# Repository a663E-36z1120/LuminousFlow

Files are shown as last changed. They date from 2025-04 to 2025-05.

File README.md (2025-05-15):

# 🌊 **Project Luminous Flow**
***Real-time fluid simulation on an LED matrix display*** responding to ***live accelerometer data***, rendered at 60+ FPS by a ***simple GPU built from scratch*** with Arduino and logic IC chips — continuum mechanics in a purely digital circuit!

<p float="left">
  
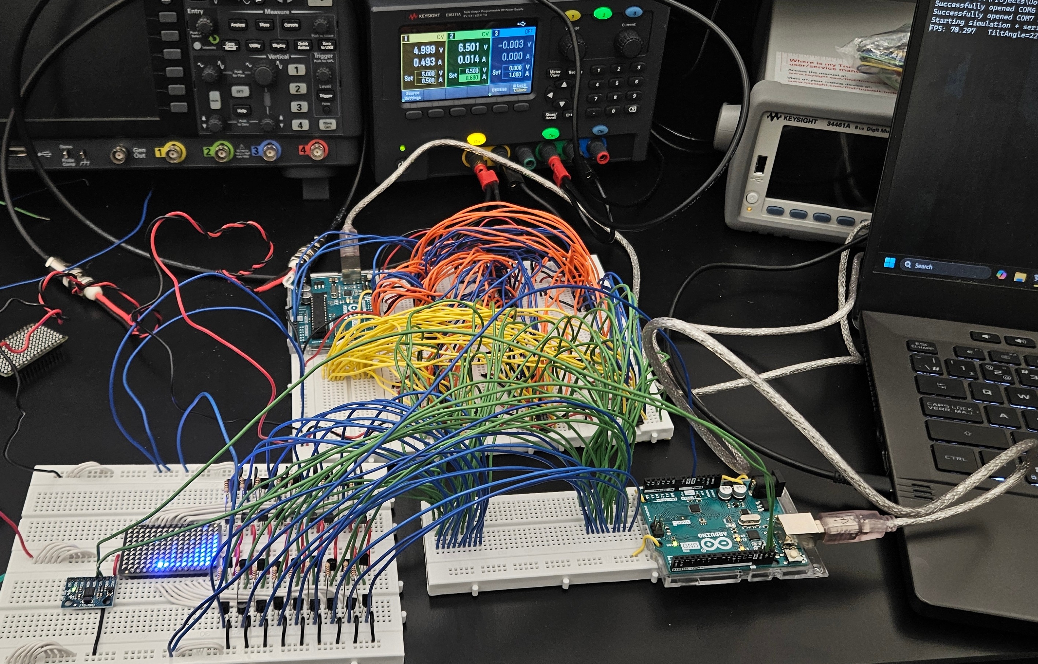
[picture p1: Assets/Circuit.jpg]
  
</p>

## Physics Engine
The physics engine of our fluid simulation implements [Smoothed-particle hydrodynamics (SPH)](https://en.wikipedia.org/wiki/Smoothed-particle_hydrodynamics) proposed by Gingold and Monaghan in 1977 [[1]](#1). This can be found in [SPHEngine.cpp](SPHEngine.cpp), which in every cycle takes as input a 2D instantaneous global acceleration in polar coordinates to update the positions of particles in the simulation.

💡 If you want to use our physics engine for your own project, we've included an isolated version of it in [Prototyping/SPHEnginePybind.cpp](Prototyping/SPHEnginePybind.cpp) that you can interact with through a Jupyter notebook such as [Prototyping/physics_testbench.ipynb](Prototyping/physics_testbench.ipynb), thanks to the [pybind11](https://github.com/pybind/pybind11) project. A Python implementation that we used in the early stages of this project is also available in [Prototyping/physics_testbench_py.ipynb](Prototyping/physics_testbench_py.ipynb).

⚠️ Please note that this physics engine is designed to be compiled and ran on a PC instead of a microcontroller.

<p float="left">
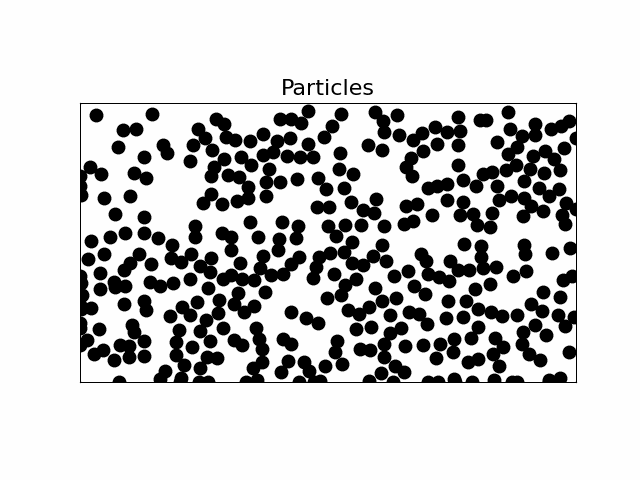
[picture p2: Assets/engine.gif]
  
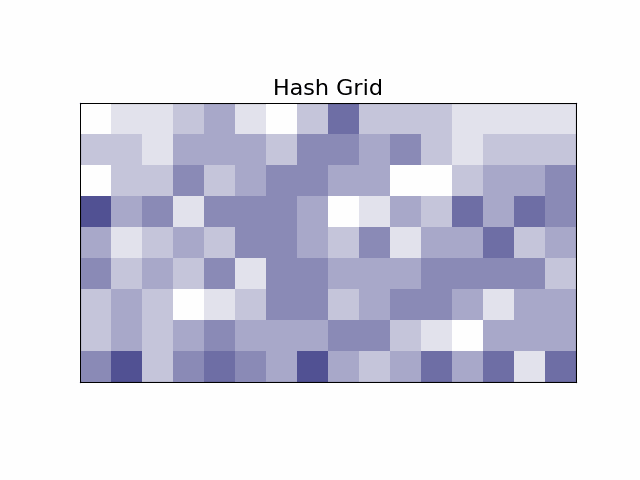
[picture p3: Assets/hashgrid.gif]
  
</p>

___

<a id="1">[[1]](https://academic.oup.com/mnras/article/181/3/375/988212)</a> 
Gingold, R. A., & Monaghan, J. J. (1977). *Smoothed particle hydrodynamics: theory and application to non-spherical stars.* Monthly notices of the royal astronomical society, 181(3), 375-389.

Created by 
[@a663E-36z1120](https://www.github.com/a663E-36z1120)
&
[@AlexZengXi](https://www.github.com/AlexZengXi); shoutout to [Prof. Ziqing Hong](https://zqhong.physics.utoronto.ca/) from the Department of Physics at University of Toronto for teaching the amazing [PHY405H1: Electronics Lab](https://artsci.calendar.utoronto.ca/course/phy405h1) course and supporting this project!

___

# **Detailed Technical Documentations for the Nerds**

*Figure 1: Project Luminous Flow in Its Entirety *

## System Architecture
We are designing an interactive LED matrix that simulates fluid motion in response to the system's tilt. Figure 2 shows the functional block diagram of the system. 

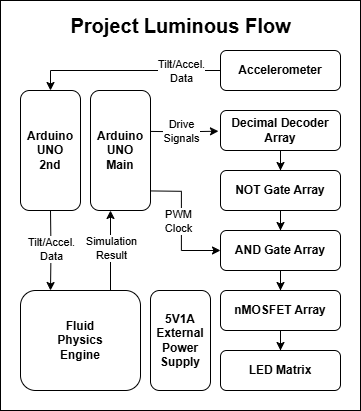
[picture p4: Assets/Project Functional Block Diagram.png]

*Figure 2: Functional Block Diagram*

As illustrated in Figure 1, the system architecture is divided into three primary sections. The far-right segment comprises four full-sized breadboards, collectively housing our custom-designed GPU. This region includes the main Arduino UNO, responsible for generating all driving signals, and the array of logic IC chips that help distribute the signals.

To the left, a pair of breadboards make up the LED display section. This section houses the 16×9 LED matrix, the accelerometer, all the nMOSFETs, and the current-limiting resistors.

Finally, the single breadboard in between acts as an interface board. It organizes the signal connections from the logic gate array to the LED display, simplifying testing and debugging. This board also holds the secondary Arduino, which relays accelerometer data to the physics engine for real-time simulation. 

The Build of Materials can be found below in Table 1.

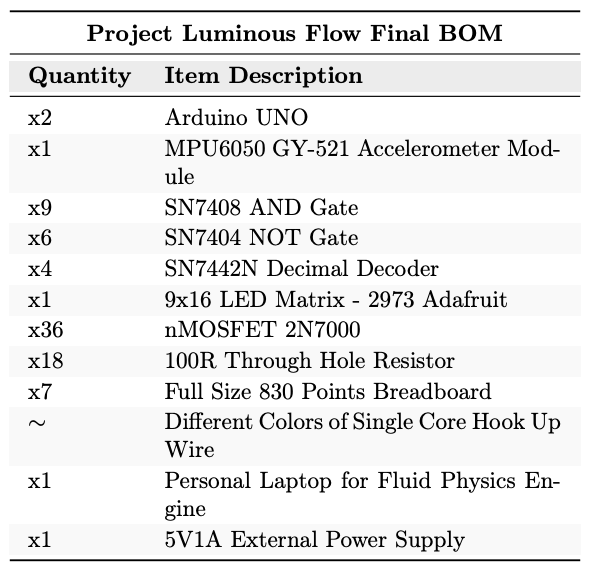
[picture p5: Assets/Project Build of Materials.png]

*Table 1: Build of Materials*

## Fluid Physics Engine
The physics engine of our fluid simulation implements Smoothed-particle hydrodynamics (SPH) as proposed by Gingold and Monaghan in 1977. Pseudo-code outlined by the Algorithm describes how our implementation of the SPH physics engine operates.

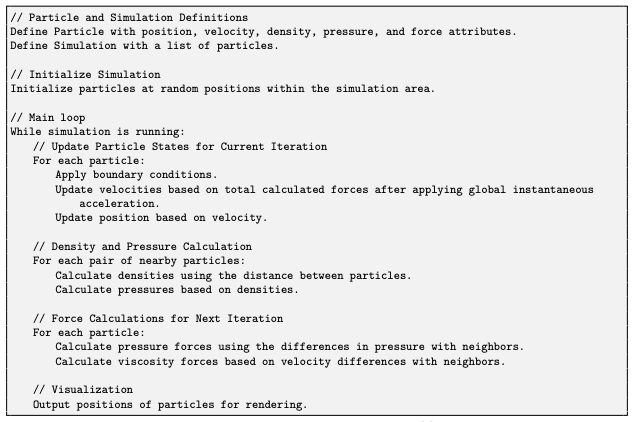
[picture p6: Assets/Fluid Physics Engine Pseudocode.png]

*Algorithm 1: Core Abstract Operations of the SPH Physics Engine*

Every cycle of our physics engine takes as input a 2D instantaneous global acceleration in polar coordinates and outputs to update the positions of particles in the simulation.

## Accelerometer
We are using an MPU6050 GY-521 Accelerometer Module. It communicates to our secondary Arduino UNO through I2C and then feeds serial data to the physics engine. Given that our simulation is 2D while our accelerometer supplies acceleration vectors in 3D, we project $\vec{a} = (x, y, z)$ onto the $xy$-plane and compute:

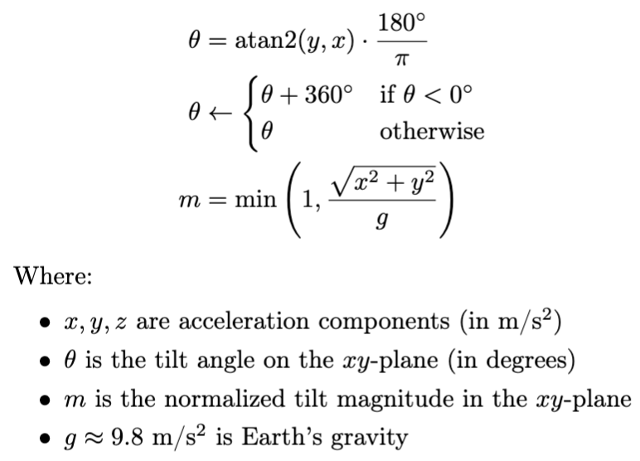
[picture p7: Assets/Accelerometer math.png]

*Algorithm 2: Core Abstract Operations of the SPH Physics Engine*

This projected and normalized polar form accelerometer data $(\theta, m)$ is what we input into our physics engine.

## Communication Protocol 
The system establishes two serial communication channels between the PC that runs the SPH physics simulation and two Arduinos. The first Arduino is connected to an MPU6050 accelerometer via I²C and continuously transmits orientation data to the PC over USB serial at 115200 baud. Each packet is 9 bytes long, consisting of a 1-byte header (0xFE), followed by two 4-byte `float` values: the tilt angle and normalized magnitude. These values are packed in little-endian order and sent as raw binary data.

On the PC side, this data is received asynchronously and used to update a real-time 2D smoothed particle hydrodynamics (SPH) simulation. The new gravity direction is derived from the received tilt values and applied to the particle system. The resulting particle positions are mapped to a $9 \times 16$ LED grid using a uniform hash grid, where local particle density is converted into brightness values in the range $[0, 255]$.

A second serial connection is established between the PC and a second Arduino responsible for controlling the LED matrix (the "GPU Arduino") also at 115200 baud. A hash grid maps continuous particle positions from the physics simulation into discrete LED grid cells by counting particle density per cell, which is then linearly scaled to individual pixel brightness in a frame. The PC sends full display frames as 145-byte binary packets, consisting of a 1-byte header (0xFF), followed by 144 brightness bytes (row-major order). These values are packed in little-endian order and sent as raw binary data. The GPU Arduino receives these frames and renders them to the physical display using a Charlieplexing scheme with bit-banged 4-bit output codes. Brightness is modulated using PWM control, allowing smooth intensity transitions.

## Graphics Processing Unit
We constructed a simple GPU from an Arduino Uno and logic IC chips listed on Table 1 to be able to render our physics engine at a frame rate that seems realistic to the naked eye on our LED matrix display. As shown on Table 3, the LED matrix display requires 36 unique digital pins to address all pixels on our display while our physics simulation will appear more compelling if we are able to control the brightness of every pixel independently. However, the Arduino Uno only has 20 GPIO pins, out of which only 6 can support PWM. Our GPU firmware overcomes this limitation by employing a bit-banging technique that encodes the signal for each half of the LED display into 4-bit binary values. Specifically, the left and right halves of the display are each driven by two sets of 4 GPIO pins—one set for the positive rail and one for the negative rail—totaling 16 GPIO pins, as shown on Table 2. For every pixel, the firmware determines a pair of 4-bit little-endian codes that specify the required output on the positive and negative rails, respectively, according to a pre-defined Charlieplexing lookup table. PWM signal to control the brightness of every pixel originates from a single pin (Pin 11).


*Table 2: Arduino Bit-Bang Pin Mapping for Addressing the Multiplexed LED Matrix. (See Table 3: Pixel Addressing) Pin 11 is used for the PWM Signal Broadcast. *

At the hardware level, each of our 4-bit encoded binary control signals from the Arduino Uno is first decoded with SN7442N decimal decoders. The SN7442N decodes our 4-bit binary control signal to one of its 10 output pins outputting low voltage while all other 9 output pins output high voltage. We want the opposite—where only 1 pin outputs high while the rest output low—so we pass the decoded signal through SN7404 hex inverters, which are effectively an array of NOT gates that invert the decoded signals to what we want. Finally, we pass this inverted signal and a broadcasted PWM signal from Pin 11 through SN7408 binary AND gates to give our control signal the desired duty cycle to control the brightness of the pixel it drives. The output from the AND gate arrays are the final digital output signals to the LED matrix display. The constructed circuit of our GPU can be seen in Figure 3.

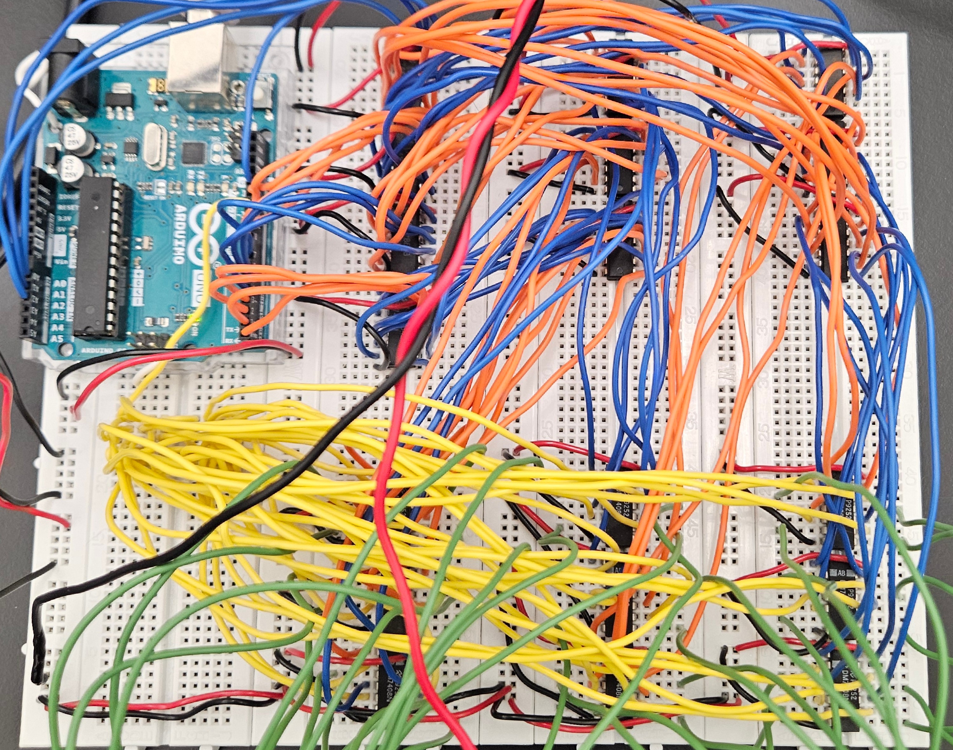
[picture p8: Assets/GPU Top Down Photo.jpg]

*Figure 3: Photo of the GPU we constructed. On the rightmost 3 breadboard columns: **top left:** 4x SN7442N decimal decoder array. **top center & top right:** 6x SN7404 hex inverter (NOT gate) array. **bottom left, center, & right:** 9x SN7408 AND gate array. Wire colors: **Orange & Blue:** internal digital signal wires, alternates every 4 bit and after passing through NOT gates. **Yellow:** PWM signal broadcast wires. **Green:** Output signal wires. **Red:** 5V Vcc. **Black:** Ground.*

## LED Matrix and nMOSFET Array
We are using the Adafruit 2973 16x9 blue LED matrix to display the behavior of water under varying tilt angles. This matrix comprises 144 individual LEDs, and driving each LED with a separate GPIO pin would be impractical. Instead, we employ a common technique called multiplexing. Specifically, this board utilizes a row-column multiplexing method. 

The 16x9 LED matrix is internally structured as two independent 8x9 LED matrices, Matrix A and Matrix B. Each of these 8x9 matrices is controlled by nine dedicated pins, as illustrated in the schematic (Figure 4 or the project's GitHub page for a higher-resolution image). Each of these nine pins is connected to a pair of 2N70000 nMOSFETs. One MOSFET, when the gate receives an activation signal, connects the pin to ground. The other MOSFET, when activated, connects the pin through a 100R current-limiting resistor to the 5V power supply. It is also worth noting that the connections for each row and column are unique and should be carefully examined. 

LEDs are unidirectional devices, meaning they only emit light when current flows through them in the forward direction. Additionally, in a multiplexed matrix, even if an LED has the correct forward voltage across it, if a lower-resistance path from another LED exists for the current, the current won't go through other LEDs. This current flow characteristic dictates how we can selectively activate individual LEDs within the matrix. 

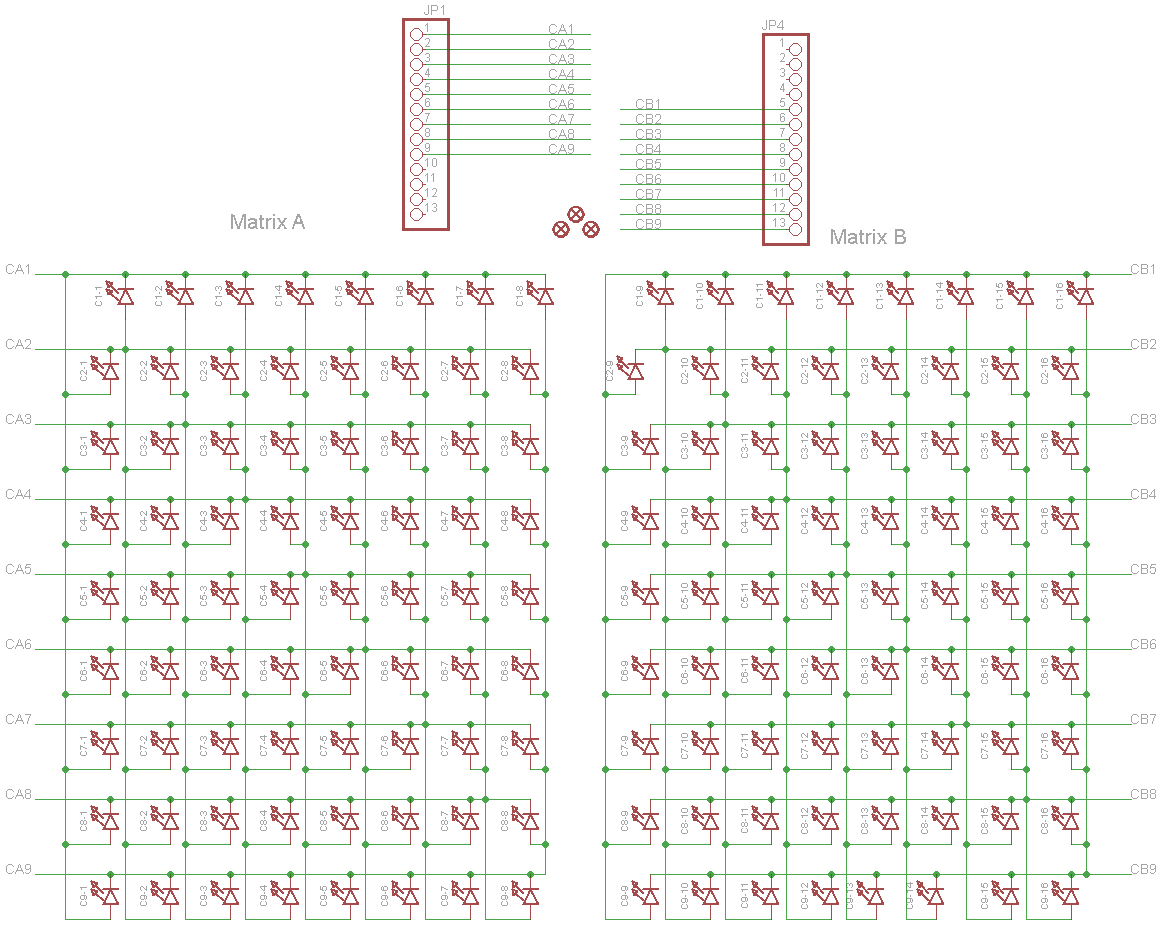
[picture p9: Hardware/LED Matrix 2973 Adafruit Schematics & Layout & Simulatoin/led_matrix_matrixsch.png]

*Figure 4: 2973 Adafruit 16x9 Blue LED Matrix Schematic*

By precisely controlling which of the nine control lines are driven high (connected to approximately 5V through a current-limiting resistor) and which are driven low (connected to ground) at any given moment, we can create a specific voltage potential across only the desired LED, ensuring current flows through it and no other unintended paths are completed. Rapidly switching these control line states allows us to create the illusion of a stable display with individual pixel control using fewer pins than the total number of LEDs. 

Each submatrix of the 16×8 LED display requires nine control pins, resulting in a total of eighteen control pins for the full board. Since each control pin is connected to two nMOSFETs, the system needs to control 36 nMOSFETs to operate the entire display. While this is still far fewer than the 128 GPIO pins that would be needed to control each LED individually, 36 GPIO pins is still beyond what an Arduino UNO can provide. Additionally, to create a more lifelike fluid simulation, we aim to vary the brightness of the LEDs—requiring 36 PWM-capable outputs, which is impractical without designing a custom shield board from scratch. 

After extensive brainstorming, we developed a simple yet effective solution using only the logic gate components available in our physics lab. More information on this is explained in the earlier GPU section. 

We use 2N7000 through-hole nMOSFETs to pull the LED display control pins high or low. The schematic for a typical control pin setup is shown in Figure \ref{p4}. All MOSFETs are controlled by the logic gate array and the Arduino, based on output from the fluid physics engine. Although the Arduino’s GPIO pins output around 5V, after passing through logic gates, various wire lengths, and the breadboard, the voltage reaching the nMOSFET gates remains above 4V, still well above the gate threshold voltage and safely below the maximum voltage rating. 

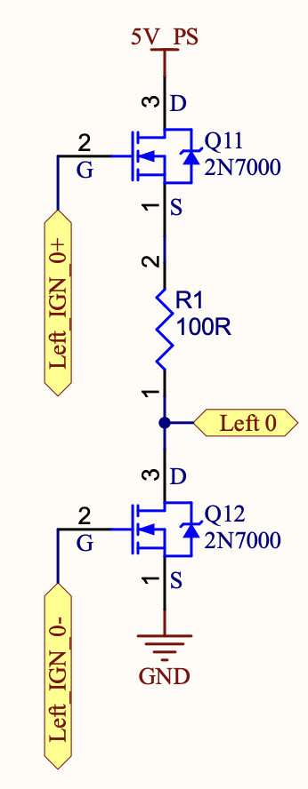
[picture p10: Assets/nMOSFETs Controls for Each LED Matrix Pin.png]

*Figure 5: Schematics of the Pull-Up and Pull-Down Setup for Control Pin 0 from the LED Matrix as Example*

When an nMOSFET receives a turn-on signal, it allows current to flow from drain to source. For the pull-up configuration, the drain is connected to the 5V rail, and the source is connected to a 100R current-limiting resistor, which then connects to the LED control pin. In the pull-down configuration, the source is connected to ground, and the drain is connected to the LED control pin. We intentionally swap the drain and source for the pull-down setup because during testing, we found that not doing so created unwanted current paths to ground, unintentionally activating multiple LEDs at once. 

In our row-column multiplexing method, to keep the firmware simple, we only turn on one LED per submatrix at a time. To create the illusion of a smooth and continuous pattern across the entire display, the system must run at a very high refresh rate. As a final precaution, we verified the switching speed of the 2N7000 MOSFETs. Both the turn-on and turn-off times are approximately 10ns \cite{2n7000}, corresponding to a theoretical switching frequency of up to 50MHz. However, accounting for real-world delays such as gate charging and discharging, we introduced a slight delay between operations. 

Since only one LED is active at any given moment, the 100R current-limiting resistor is selected based on the current requirements of a single blue LED operating at 5V. 

To simplify debugging and quickly determine which pins need to be pulled high or low, we created a lookup table, as shown in Table 3. This table is then used in the firmware to control the corresponding MOSFETs for each LED.

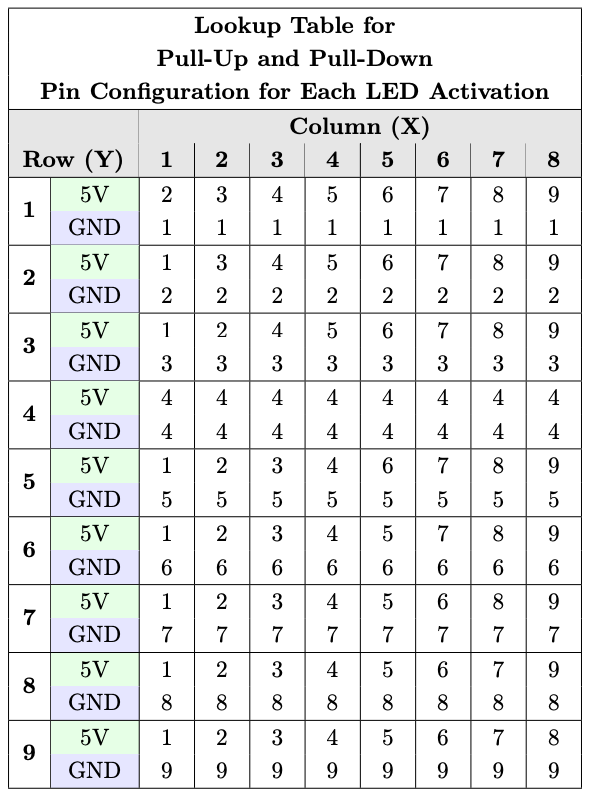
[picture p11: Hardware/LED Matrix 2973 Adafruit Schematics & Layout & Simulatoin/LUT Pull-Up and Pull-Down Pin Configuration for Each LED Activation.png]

*Table 3: Configuration values for LED matrix control. For each LED position, the table shows which pins should be set to 5V and which to GND*

## Power Supply
For this project, we used a Keysight E36311A as an external power supply. As a safety precaution, we powered the LED display and the accelerometer using one 5V channel, while a second 5V channel supplied power to the rest of the system. Using two separate channels allowed us to monitor the current draw of each section independently, which proved helpful during debugging. 

Since only one LED is active at a time, the power consumption of the first 5V channel remained very low, drawing less than 10mA in total. However, the logic gate array drew approximately 0.5A, far exceeding what the Arduino UNOs can provide. This made an external power supply essential for everything to work. 

Although the power supply may not deliver exactly 5V, small ripples and voltage offsets are still within the acceptable range to reliably power our entire system. Similarly, while the current readings may not be perfectly accurate, they are sufficient for identifying anomalies. In practice, if something is wired incorrectly, the current draw typically spikes and quickly hits the 0.6A current limit, providing a clear indication that something is wrong. 

Both 5V channels from the external power supply and the two Arduino UNOs share a common ground to ensure proper signal referencing and avoid potential floating ground issues.

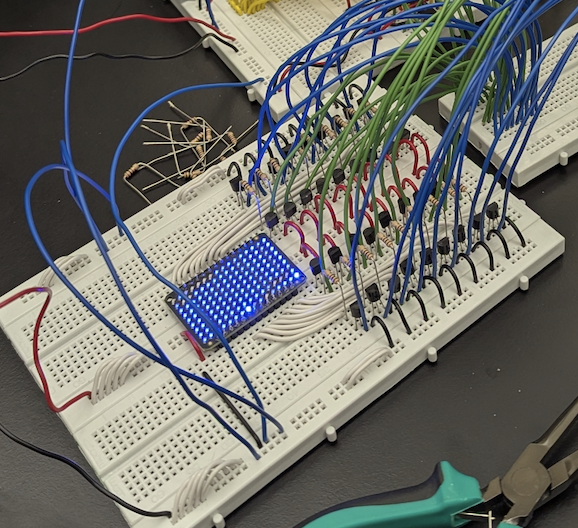
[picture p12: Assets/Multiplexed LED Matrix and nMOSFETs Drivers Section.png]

*Figure 6: Photo of the LED Display and Driver Section, consists of 36x 2N7000 nMOSFETs, 16x 100R Resistors and the LED display. (the accelerometer is missing in this photo). Wire colors: **Green & Blue on the right:** nMOSFETs' gate signal wires connecting to the interface board. **White:** Wires Connecting to the LED display. **Red:** 5V Power Supply. **Black:** Ground.**

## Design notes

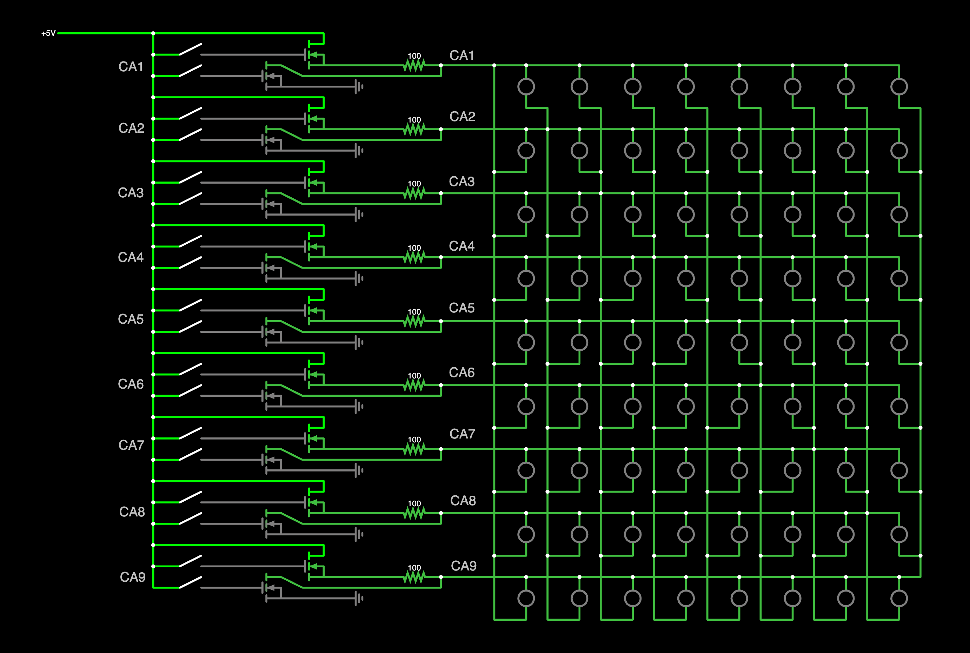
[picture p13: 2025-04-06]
Hardware/LED Matrix 2973 Adafruit Schematics & Layout & Simulatoin/LED Matrix and Drivers Falstad Simulation Screenshot.png

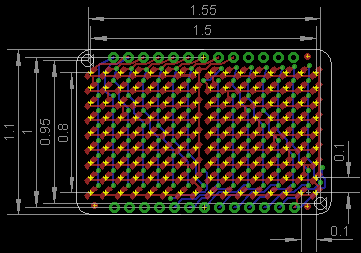
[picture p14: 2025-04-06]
Hardware/LED Matrix 2973 Adafruit Schematics & Layout & Simulatoin/led_matrix_schemgrid.png

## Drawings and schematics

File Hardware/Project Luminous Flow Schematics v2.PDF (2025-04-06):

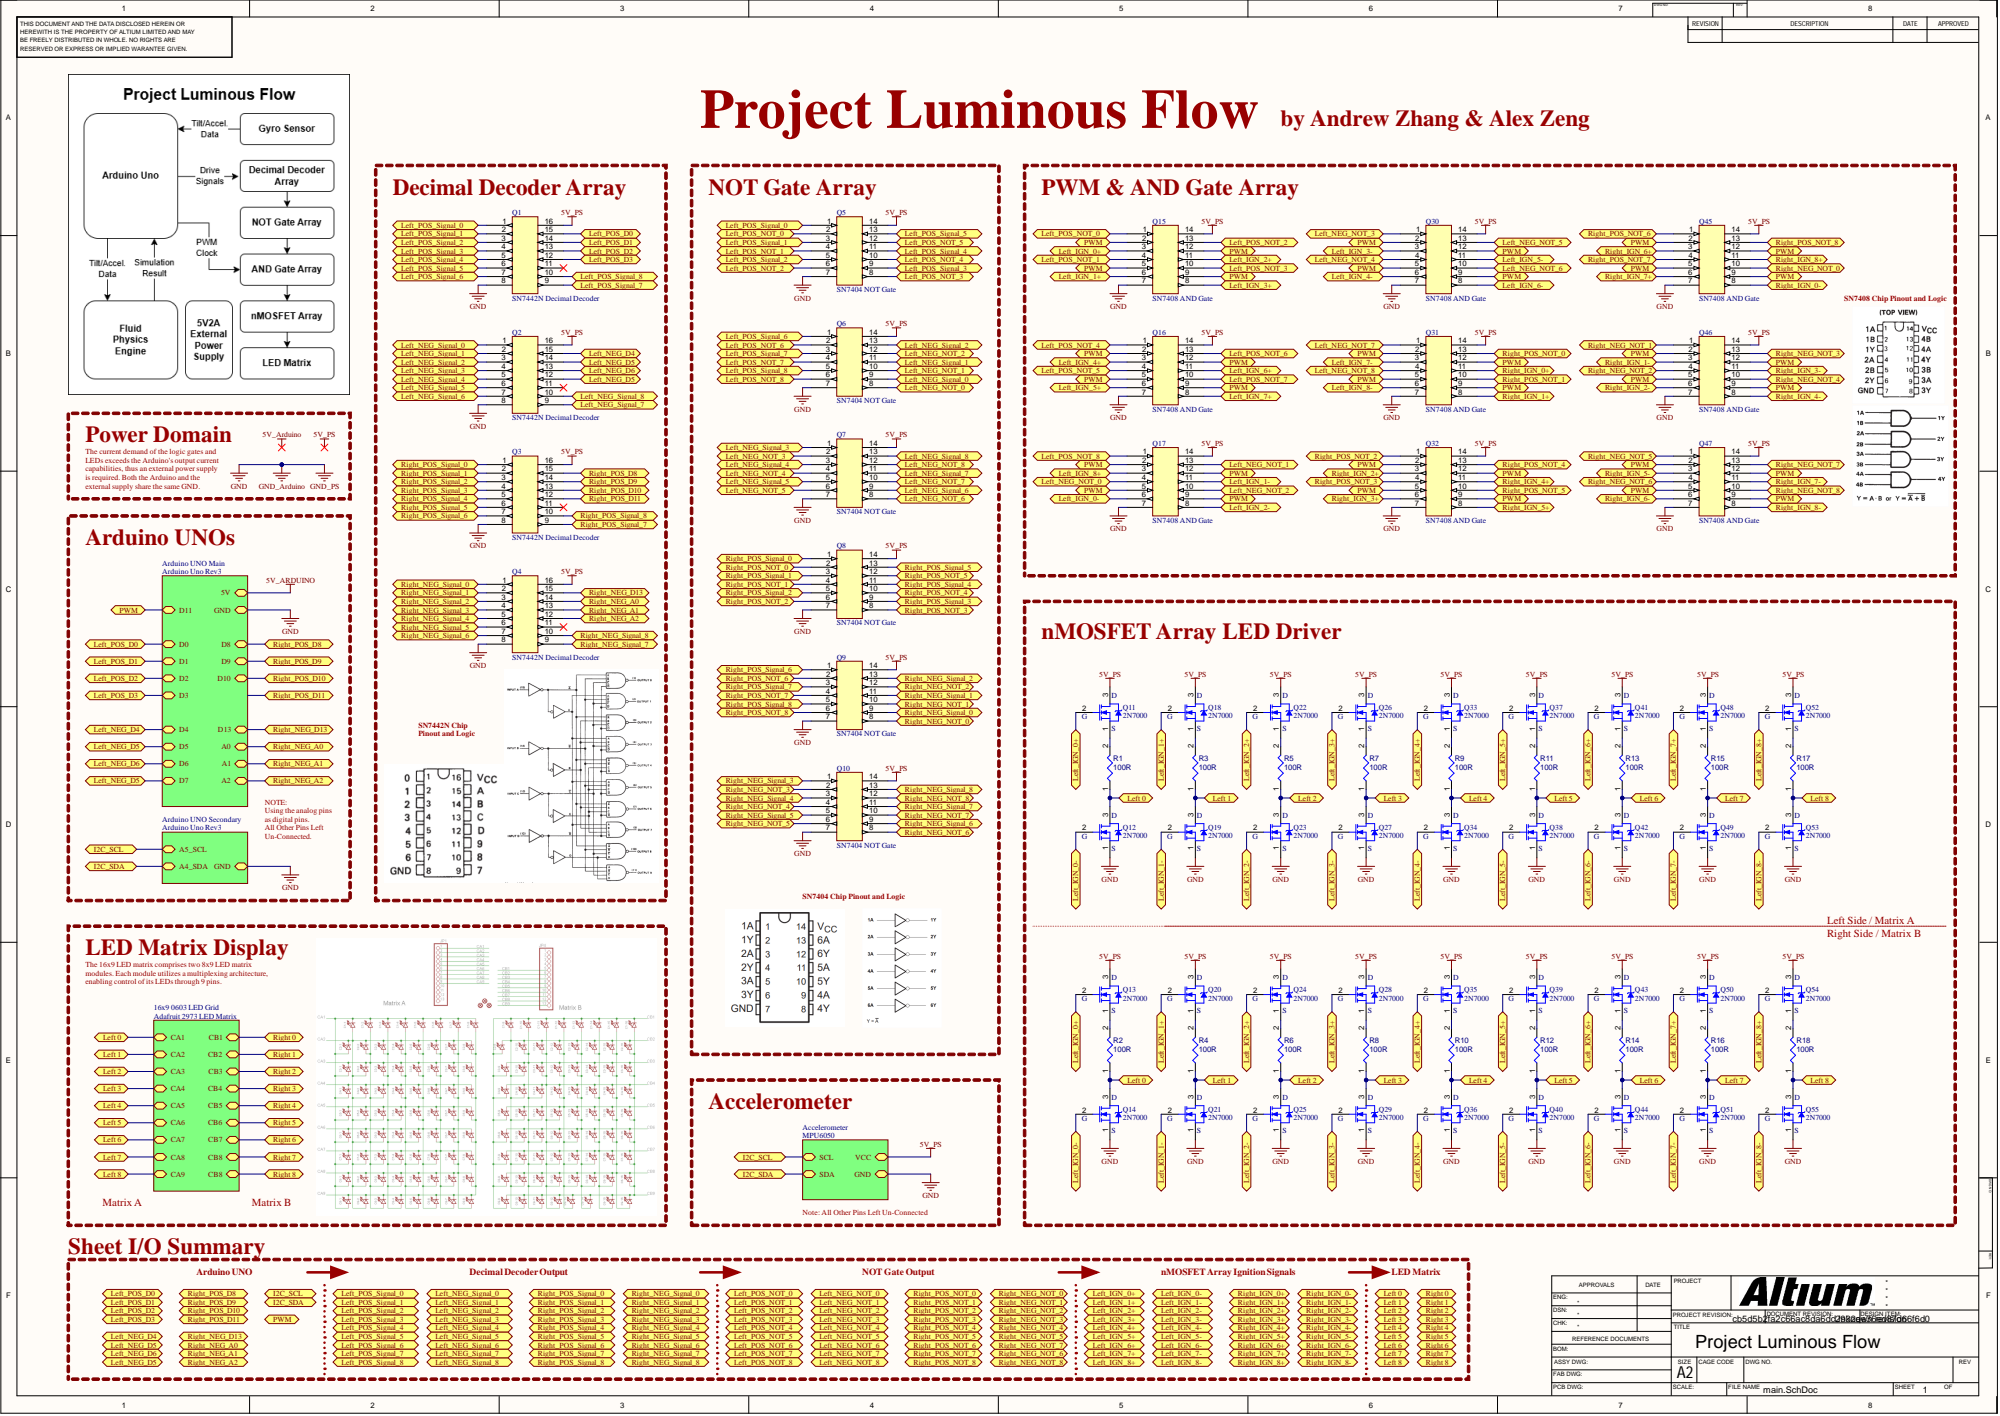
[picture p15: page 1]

DWG NO: | REV:

THIS DOCUMENT AND THE DATA DISCLOSED HEREIN OR HEREWITH IS THE PROPERTY OF ALTIUM LIMITED AND MAY BE FREELY DISTRIBUTED IN WHOLE. NO RIGHTS ARE RESERVED OR EXPRESS OR IMPLIED WARANTEE GIVEN. | Project Luminous Flow by Andrew Zhang & Alex Zeng PWM & AND Gate Array Q5 5V_PS | REVISION | DESCRIPTION | DATE | APPROVED

SN7408 Chip Pinout and Logic

The current demand of the logic gates and
LEDs exceeds the Arduino's output current
capabilities, thus an external power supply
is required. Both the Arduino and the
external supply share the same GND.

nMOSFET Array LED Driver

NOTE:
Using the analog pins
as digital pins.
All Other Pins Left
Un-Connected.

SN7404 Chip Pinout and Logic

The 16x9 LED matrix comprises two 8x9 LED matrix
modules. Each module utilizes a multiplexing architecture,
enabling control of its LEDs through 9 pins.

Note: All Other Pins Left Un-Connected

DATE | PROJECT | * * APPROVALS * *

ENG: *

DSN: *

CHK: *

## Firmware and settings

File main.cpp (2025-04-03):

#include <windows.h>
#include <iostream>
#include <string>
#include <chrono>
#include <thread>
#include <vector>
#include <cmath>

// -----------------------------------------------------------------------------
// Global/Top-Level Variables
// -----------------------------------------------------------------------------

static const int LED_ROWS = 9;
static const int LED_COLS = 16;
static const int VAR_INTENSITY = 10; 
static const int HALF_COLS = 8;

static const double CELL_SIZE = 0.1;
static const int N = 250;

// For reading accelerometer data:
static const BYTE ACCEL_HEADER = 0xFE; 
static const int ACCEL_PACKET_SIZE = 9;  // 1 + 8 (two floats)

// -----------------------------------------------------------------------------
// Include Physics Engine
// -----------------------------------------------------------------------------
#include "SPHEngine.cpp"

// -----------------------------------------------------------------------------
// Helper to open and configure the serial port on Windows.
// -----------------------------------------------------------------------------
HANDLE openSerialPort(const char* portName, DWORD baudRate = CBR_115200) {
    HANDLE hSerial = CreateFileA(
        portName,
        GENERIC_READ | GENERIC_WRITE,
        0,
        NULL,
        OPEN_EXISTING,
        0,
        NULL
    );

    if (hSerial == INVALID_HANDLE_VALUE) {
        std::cerr << "Error opening port " << portName << std::endl;
        return INVALID_HANDLE_VALUE;
    }

    // Configure serial
    DCB dcbSerialParams = {0};
    dcbSerialParams.DCBlength = sizeof(dcbSerialParams);
    if (!GetCommState(hSerial, &dcbSerialParams)) {
        std::cerr << "Failed to get current serial parameters." << std::endl;
        CloseHandle(hSerial);
        return INVALID_HANDLE_VALUE;
    }

    dcbSerialParams.BaudRate = baudRate;
    dcbSerialParams.ByteSize = 8;
    dcbSerialParams.Parity   = NOPARITY;
    dcbSerialParams.StopBits = ONESTOPBIT;

    if (!SetCommState(hSerial, &dcbSerialParams)) {
        std::cerr << "Failed to set serial parameters." << std::endl;
        CloseHandle(hSerial);
        return INVALID_HANDLE_VALUE;
    }

    COMMTIMEOUTS timeouts = {0};
    timeouts.ReadIntervalTimeout         = 50;
    timeouts.ReadTotalTimeoutConstant    = 1000;
    timeouts.ReadTotalTimeoutMultiplier  = 10;
    timeouts.WriteTotalTimeoutConstant   = 1000;
    timeouts.WriteTotalTimeoutMultiplier = 10;
    if (!SetCommTimeouts(hSerial, &timeouts)) {
        std::cerr << "Failed to set timeouts." << std::endl;
        CloseHandle(hSerial);
        return INVALID_HANDLE_VALUE;
    }

    std::cout << "Successfully opened " << portName << " at baud " << baudRate << std::endl;
    return hSerial;
}

// -----------------------------------------------------------------------------
// Try to read a 9-byte packet: [0xFE][float angle][float magnitude]
// Returns true if we got a full packet. On success, outputs angle & magnitude.
// -----------------------------------------------------------------------------
bool readTiltData(HANDLE hSerial, float &angleDeg, float &magnitude) {
    COMSTAT stat;
    DWORD errors;
    ClearCommError(hSerial, &errors, &stat);

    DWORD bytesAvailable = stat.cbInQue;
    if (bytesAvailable < ACCEL_PACKET_SIZE) {
        return false; // Not enough data
    }

    // Read all available bytes (up to a safe max)
    const DWORD MAX_READ = 1024;
    uint8_t buffer[MAX_READ];
    DWORD bytesToRead = (bytesAvailable > MAX_READ) ? MAX_READ : bytesAvailable;
    DWORD bytesRead = 0;

    if (!ReadFile(hSerial, buffer, bytesToRead, &bytesRead, NULL) || bytesRead == 0) {
        return false;
    }

    // Search for the last valid packet (from end to start)
    for (int i = bytesRead - ACCEL_PACKET_SIZE; i >= 0; --i) {
        if (buffer[i] == ACCEL_HEADER) {
            // Found a possible packet
            union FloatBytes {
                float f;
                uint8_t b[4];
            } angleData, magData;

            for (int j = 0; j < 4; ++j)
                angleData.b[j] = buffer[i + 1 + j];
            for (int j = 0; j < 4; ++j)
                magData.b[j] = buffer[i + 5 + j];

            angleDeg = angleData.f;
            magnitude = magData.f;
            return true;
        }
    }

    return false; // No valid packet found
}

// -----------------------------------------------------------------------------
// HashGrid for converting SPH positions -> LED brightness
// -----------------------------------------------------------------------------
void hashGrid(const std::vector<double>& positions,
              unsigned char ledFrame[LED_ROWS][LED_COLS])
{
    // 1) Clear out ledFrame
    for (int r = 0; r < LED_ROWS; r++) {
        for (int c = 0; c < LED_COLS; c++) {
            ledFrame[r][c] = 0;
        }
    }

    // 2) Internal accumulators
    int counts[LED_ROWS][LED_COLS];
    for (int r = 0; r < LED_ROWS; r++) {
        for (int c = 0; c < LED_COLS; c++) {
            counts[r][c] = 0;
        }
    }

    // 3) For each particle
    for (size_t i = 0; i + 1 < positions.size(); i += 2) {
        double x = positions[i];
        double y = positions[i+1];

        int x_index = static_cast<int>((x + SIM_W) / CELL_SIZE);
        int y_index = static_cast<int>(y / CELL_SIZE);

        if (x_index >= 0 && x_index < LED_COLS &&
            y_index >= 0 && y_index < LED_ROWS)
        {
            counts[y_index][x_index]++;
        }
    }

    // 4) Convert counts to brightness
    for (int r = 0; r < LED_ROWS; r++) {
        for (int c = 0; c < LED_COLS; c++) {
            int countVal = counts[r][c];
            if (countVal >= VAR_INTENSITY) {
                countVal = VAR_INTENSITY - 1;
            }
            int brightness = static_cast<int>(countVal * (255.0 / (VAR_INTENSITY - 1)));
            ledFrame[r][c] = static_cast<unsigned char>(brightness);
        }
    }
}

// -----------------------------------------------------------------------------
// Send a 9×16 LED frame in binary: [0xFF] + 144 brightness bytes
// -----------------------------------------------------------------------------
void sendFrameToArduino(HANDLE hSerial, const unsigned char ledFrame[LED_ROWS][LED_COLS]) {
    static const BYTE HEADER = 0xFF;
    static const int TOTAL_BYTES = 1 + (LED_ROWS * LED_COLS); // 145

    unsigned char framePacket[TOTAL_BYTES];
    framePacket[0] = HEADER;

    int index = 1;
    for (int r = 0; r < LED_ROWS; r++) {
        for (int c = 0; c < LED_COLS; c++) {
            framePacket[index++] = ledFrame[r][c];
        }
    }

    DWORD bytesWritten;
    WriteFile(hSerial, framePacket, TOTAL_BYTES, &bytesWritten, NULL);
}

// -----------------------------------------------------------------------------
// Main
// -----------------------------------------------------------------------------
int main() {
    // 1) Open COM ports
    // COM port for graphics
    const char* portNameGPU = "COM6";  // Adjust as needed
    HANDLE hSerialGPU = openSerialPort(portNameGPU, CBR_115200);
    if (hSerialGPU == INVALID_HANDLE_VALUE) {
        return 1;
    }

    // COM port for accl
    const char* portNameAcc = "COM7";  // Adjust as needed
    HANDLE hSerialAcc = openSerialPort(portNameAcc, CBR_115200);
    if (hSerialAcc == INVALID_HANDLE_VALUE) {
        return 1;
    }

    // 2) Create SPH simulation
    Simulation sim(N, -SIM_W, SIM_W, BOTTOM, TOP);

    // 3) Frame buffer
    static unsigned char ledFrame[LED_ROWS][LED_COLS];

    std::cout << "Starting simulation + serial with Arduino(s)...\n";

    // We'll store the tilt angle (deg) and magnitude from Arduino
    float tiltAngleDeg  = 0.0f;
    float tiltMagnitude = 0.0f;

    // For FPS logging
    int frameCount = 0;
    auto lastTime = std::chrono::steady_clock::now();
    double fps = 0.0;

    while (true) {
        // a) Attempt to read accelerometer data (non-blocking)
        if (readTiltData(hSerialAcc, tiltAngleDeg, tiltMagnitude)) {
            // std::cout << "\rTiltAngle=" << tiltAngleDeg 
            // << " deg  TiltMag=" << tiltMagnitude 
            // << "     " << std::flush;
            // If we got new data, convert angle to radians, magnitude in [0..1]
            double angleRad = ((tiltAngleDeg) * -1 - 90)* M_PI / 180.0;
            double dynGmag  = tiltMagnitude * G_MAG; 
            sim.update(G_MAG, angleRad);
        }
        
        //  else {
        //     // If no new data, we can keep last tilt or fallback to default
        //     sim.update(G_MAG, G_ANG);
        // }

        // b) Get updated particle positions
        std::vector<double> positions = sim.get_visual_positions();

        // c) Convert to 9×16 brightness
        hashGrid(positions, ledFrame);

        // d) Send to Arduino
        sendFrameToArduino(hSerialGPU, ledFrame);

        // e) FPS logging
        frameCount++;
        auto now = std::chrono::steady_clock::now();
        auto elapsedMs = std::chrono::duration_cast<std::chrono::milliseconds>(now - lastTime).count();
        if (elapsedMs >= 1000) {
            fps = frameCount / (elapsedMs / 1000.0);
            frameCount = 0;
            lastTime = now;
        }
        std::cout << "\rFPS: " << fps << "   TiltAngle=" << tiltAngleDeg 
                  << " deg  TiltMag=" << tiltMagnitude << "     " << std::flush;
    }

    CloseHandle(hSerialGPU);
    CloseHandle(hSerialAcc);
    return 0;
}

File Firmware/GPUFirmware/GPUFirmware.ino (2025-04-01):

#include <Arduino.h>

//----------------------------------------------------------
// Constants
//----------------------------------------------------------
#define ROWS 9       // Number of rows
#define COLS 8       // Number of columns per half
#define HALVES 2     // Left half + Right half

// For receiving the new binary protocol: 1 header + 144 brightness bytes = 145
#define LED_ROWS 9   // 9 total rows
#define LED_COLS 16  // 16 total columns (8 per half)
#define FRAME_SIZE  (1 + LED_ROWS * LED_COLS)  // 145
#define FRAME_HEADER 0xFF

//----------------------------------------------------------
// Charlie-Plex Mapping Array
//----------------------------------------------------------
// Each element is an integer (0–15), interpreted as a 4-bit value.
// For example, if the value is 8 (binary 1000), then when bit-banged onto 4 pins,
// only the highest-order bit (bit 3) will be HIGH while bits 0–2 are LOW.
const int charliePlexMap[ROWS][2][COLS] = {
  { // Row 0
    {1, 2, 3, 4, 5, 6, 7, 8},    
    {0, 0, 0, 0, 0, 0, 0, 0}     
  },
  { // Row 1
    {0, 2, 3, 4, 5, 6, 7, 8},
    {1, 1, 1, 1, 1, 1, 1, 1}
  },
  { // Row 2
    {0, 1, 3, 4, 5, 6, 7, 8},
    {2, 2, 2, 2, 2, 2, 2, 2}
  },
  { // Row 3
    {0, 1, 2, 4, 5, 6, 7, 8},
    {3, 3, 3, 3, 3, 3, 3, 3}
  },
  { // Row 4
    {0, 1, 2, 3, 5, 6, 7, 8},
    {4, 4, 4, 4, 4, 4, 4, 4}
  },
  { // Row 5
    {0, 1, 2, 3, 4, 6, 7, 8},
    {5, 5, 5, 5, 5, 5, 5, 5}
  },
  { // Row 6
    {0, 1, 2, 3, 4, 5, 7, 8},
    {6, 6, 6, 6, 6, 6, 6, 6}
  },
  { // Row 7
    {0, 1, 2, 3, 4, 5, 6, 8},
    {7, 7, 7, 7, 7, 7, 7, 7}
  },
  { // Row 8
    {0, 1, 2, 3, 4, 5, 6, 7},
    {8, 8, 8, 8, 8, 8, 8, 8}
  }
};

//----------------------------------------------------------
// Data Structures
//----------------------------------------------------------
struct Pixel {
  int x;  // 0-indexed column (0..7 within its half)
  int y;  // 0-indexed row (0..8)
  int a;  // brightness (0–255)
};

struct CharliePlexPins {
  int pos; // mapping value (0–15) for positive side
  int neg; // mapping value (0–15) for negative side
};

//----------------------------------------------------------
// Helper Functions
//----------------------------------------------------------

// Returns the mapping values (4-bit number) for the given pixel.
CharliePlexPins getPinsForPixel(const Pixel &pixel) {
  CharliePlexPins cp;
  cp.pos = charliePlexMap[pixel.y][0][pixel.x];
  cp.neg = charliePlexMap[pixel.y][1][pixel.x];
  return cp;
}

// Bit-bangs a 4-bit integer value onto an array of 4 pins.
void setBitBangOutput(const int pins[4], int value) {
  for (int i = 0; i < 4; i++) {
    if (value & (1 << i)) {
      digitalWrite(pins[i], HIGH);
    } else {
      digitalWrite(pins[i], LOW);
    }
  }
}

//----------------------------------------------------------
// Pin Definitions for Bit-Banging
//----------------------------------------------------------
// Left half: positive side pins: D0–D3; negative side pins: D4–D7
const int leftPosPins[4] = {0, 1, 2, 3};
const int leftNegPins[4] = {4, 5, 6, 7};

// Right half: positive side pins: D8, D9, D10, D12; negative side pins: D13, A0, A1, A2
const int rightPosPins[4] = {8, 9, 10, 12};
const int rightNegPins[4] = {13, A0, A1, A2};

//----------------------------------------------------------
// Pixel Output Functions
//----------------------------------------------------------

// Outputs a pixel on the left half
void outputLeftPixel(const Pixel &pixel) {
  analogWrite(11, pixel.a);
  CharliePlexPins cp = getPinsForPixel(pixel);
  setBitBangOutput(leftPosPins, cp.pos);
  setBitBangOutput(leftNegPins, cp.neg);
}

// Outputs a pixel on the right half
void outputRightPixel(const Pixel &pixel) {
  analogWrite(11, pixel.a);
  CharliePlexPins cp = getPinsForPixel(pixel);
  setBitBangOutput(rightPosPins, cp.pos);
  setBitBangOutput(rightNegPins, cp.neg);
}

//----------------------------------------------------------
// Global Frame Array
//----------------------------------------------------------
// The full display is 9×16, split into two halves (left and right),
// each with 9 rows and 8 columns.
Pixel frame[HALVES][ROWS][COLS];

// Refreshes the display by scanning through each half & pixel
void refreshFrame(Pixel frameArray[][ROWS][COLS]) {
  // Process left half (index 0)
  for (int y = 0; y < ROWS; y++) {
    for (int x = 0; x < COLS; x++) {
      if (frameArray[0][y][x].a > 0) {
        outputLeftPixel(frameArray[0][y][x]);
      }
    }
  }
  // Process right half (index 1)
  for (int y = 0; y < ROWS; y++) {
    for (int x = 0; x < COLS; x++) {
      if (frameArray[1][y][x].a > 0) {
        outputRightPixel(frameArray[1][y][x]);
      }
    }
  }
}

//----------------------------------------------------------
// Parsing the New Binary Protocol
//----------------------------------------------------------

// We'll buffer 145 bytes: 1 header (0xFF) + 144 brightness bytes
static uint8_t serialBuffer[FRAME_SIZE];
static int bufferIndex = 0;

// Reads new frames from Serial (if available)
void parseSerial() {
  while (Serial.available()) {
    uint8_t incoming = Serial.read();

    // If this is the first byte in a potential frame, we expect 0xFF
    if (bufferIndex == 0 && incoming != FRAME_HEADER) {
      // Not the correct header, ignore and keep waiting
      continue;
    }

    // Store the incoming byte
    serialBuffer[bufferIndex++] = incoming;

    // If we've collected all 145 bytes, we have a complete frame
    if (bufferIndex == FRAME_SIZE) {
      // Decode the brightness data into our global 'frame'
      int offset = 1; // skip the 0xFF header

      for (int row = 0; row < LED_ROWS; row++) {
        for (int col = 0; col < LED_COLS; col++) {
          uint8_t brightness = serialBuffer[offset++];
          
          // Figure out which half (0 or 1), and the column within that half
          int half = (col < COLS) ? 0 : 1;
          int colInHalf = (half == 0) ? col : (col - COLS);

          // Update the Pixel object
          frame[half][row][colInHalf].a = brightness;
        }
      }

      // Done reading this frame
      bufferIndex = 0;
    }
  }
}
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

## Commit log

2025-04-01 interfacing between physics engine and graphics driver
2025-04-01 pseudo framerate logging ver 2
2025-04-02 refactoring + Gyro inputs
2025-04-02 dedicated gyro firmware
2025-04-06 Uploading Documentations
    [Alex_FluidMotionLEDMatrix.PrjPcb, main.SchDoc]
2025-04-06 garbage collection
    [Alex_FluidMotionLEDMatrix.PrjPcb, main.SchDoc]
